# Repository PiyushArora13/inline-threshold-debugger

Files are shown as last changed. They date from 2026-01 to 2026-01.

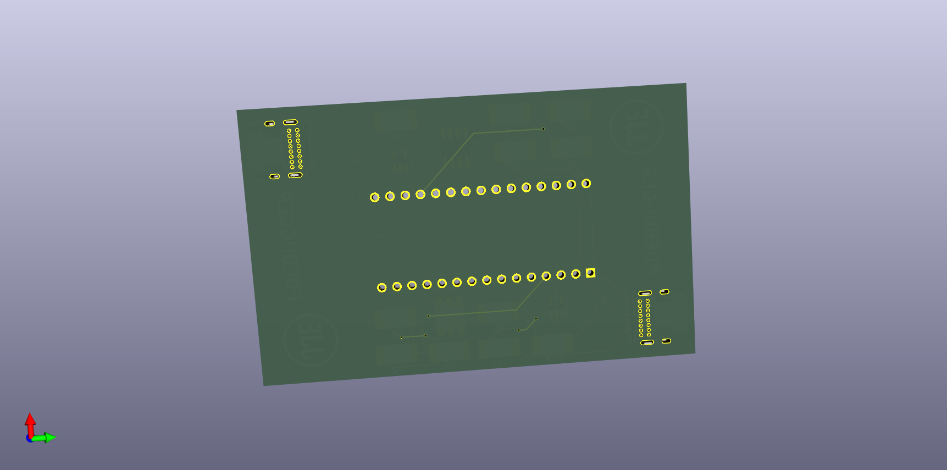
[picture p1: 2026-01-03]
Images/Bottom View.png

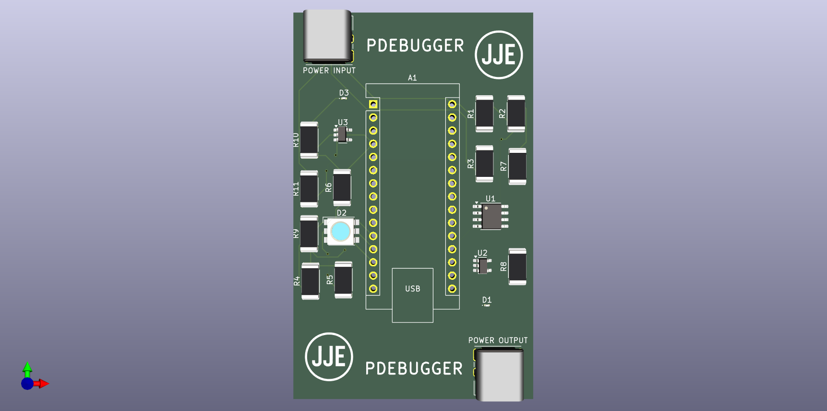
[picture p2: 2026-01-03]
Images/Top View.png

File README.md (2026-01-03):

# inline-threshold-debugger

Non-Intrusive USB-C Inline Diagnostic PCB for Master–Slave Systems

# Overview

This project presents a non-intrusive inline hardware debugger PCB designed for master–slave embedded architectures, where continuous electrical monitoring is required without altering normal system behavior. The board is placed directly in-line between master and slave nodes, enabling real-time observation of voltage and current characteristics while preserving signal integrity.

The design focuses on high-impedance sensing and comparator-based threshold detection, ensuring that monitored signals experience minimal loading and no functional disturbance. This approach allows the debugger to operate transparently within active systems, making it suitable for live diagnostics, validation, and safety monitoring.

A USB Type-C pass-through interface is used for both input and output, providing a compact, reversible, and standardized physical layer compatible with modern embedded and robotics platforms.

# System Architecture

The PCB is built around an Arduino Nano (ATmega328P), which serves as the central processing unit for data acquisition, threshold evaluation, and status indication. The microcontroller samples analog signals via its ADC and coordinates with dedicated comparator stages to classify operating conditions deterministically.

Current sensing is implemented using the ACS712 Hall-effect current sensor, providing galvanically isolated measurement with low insertion impact on the monitored path. This enables accurate current monitoring while maintaining electrical separation and system safety.

Voltage monitoring is achieved through a high-impedance sensing network followed by comparator stages configured with predefined threshold levels. Comparator outputs allow fast detection of limit violations independent of firmware execution latency, ensuring reliable indication under transient conditions.

The inline signal path is designed to maintain impedance continuity between master and slave devices, allowing the debugger PCB to function as a transparent diagnostic layer rather than an active system element.

# Threshold Evaluation and Visual Indication

Measured voltage and current parameters are continuously evaluated against predefined threshold regions. The system provides immediate visual feedback through:

Discrete LEDs indicating individual threshold events

An RGB LED representing overall system state:

Green – Normal / safe operating region

Yellow – Warning or near-limit condition

Red – Critical or unsafe operating condition

This hardware-level indication enables rapid fault identification without requiring external instruments or software-based debugging tools.

# Design Intent and Rationale

Non-intrusive monitoring: High-impedance sensing and isolated current measurement prevent disturbance of the original signal path.

Comparator-based thresholding: Ensures fast, deterministic response independent of microcontroller timing.

Inline architecture: Allows real-time diagnostics in active master–slave systems.

USB Type-C interface: Provides a compact, reversible, and standardized physical connection.

Separation of sensing and indication: Improves robustness and simplifies system-level fault analysis.

# Applications

Inline debugging of master–slave embedded systems

Power and signal integrity validation

Current and voltage health monitoring

Safety threshold enforcement in robotics and control systems

Rapid fault detection during system integration and testing

Project Status

Hardware: Prototype PCB designed and validated

Firmware: Threshold evaluation and visual indication logic implemented

Future work: Data logging, configurable thresholds, and host-side visualization

# Note on File Viewing

KiCad design files are stored in source format and are not rendered by GitHub. Please clone or download the repository and open it in KiCad to view schematics and PCB layouts. Rendered images are included for reference

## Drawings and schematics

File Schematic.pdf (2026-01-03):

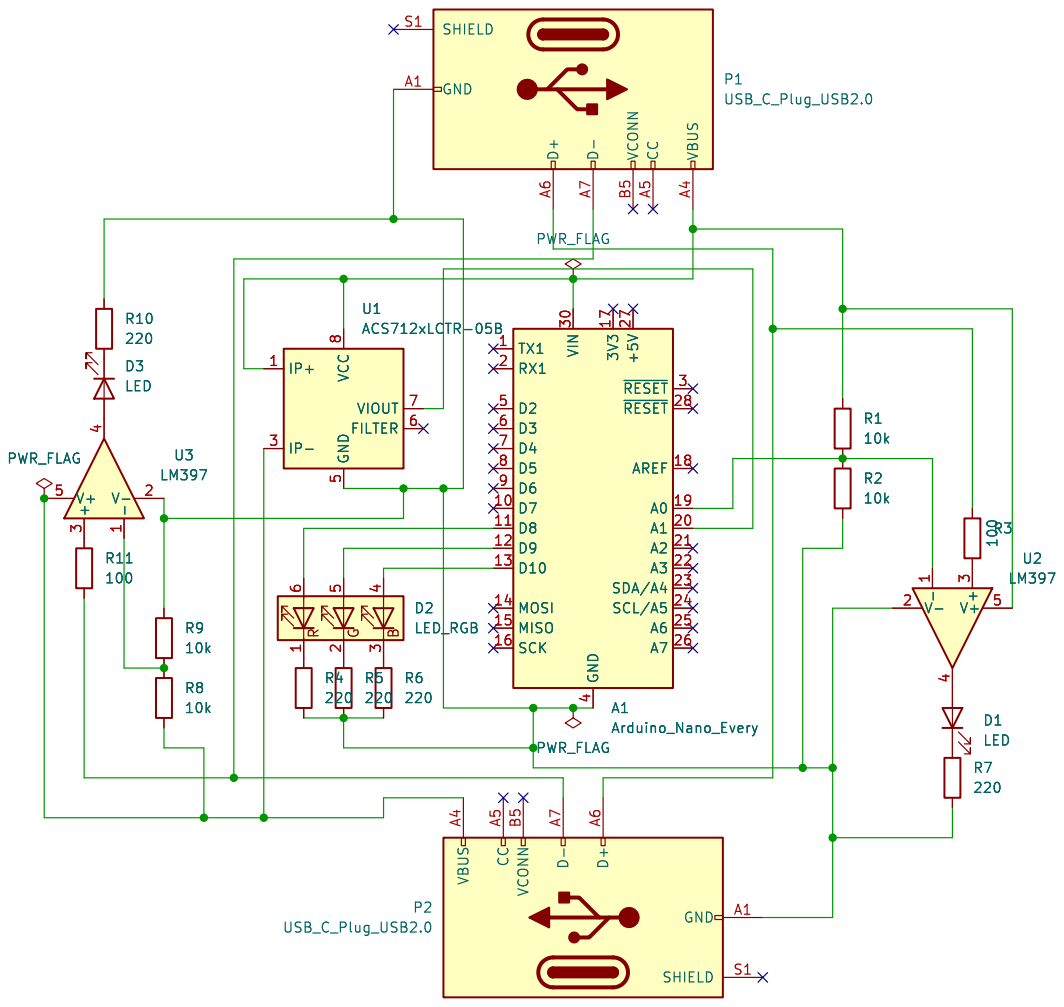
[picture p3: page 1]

4 D2 5 D3 6 D4 7 D5 8 D6 9 A1Arduino_Nano_Every GND A1 VBUS A4 CC A5 D+ A6 D- A7 VCONN B5 SHIELD S1 P1USB_C_Plug_USB2.0 R4

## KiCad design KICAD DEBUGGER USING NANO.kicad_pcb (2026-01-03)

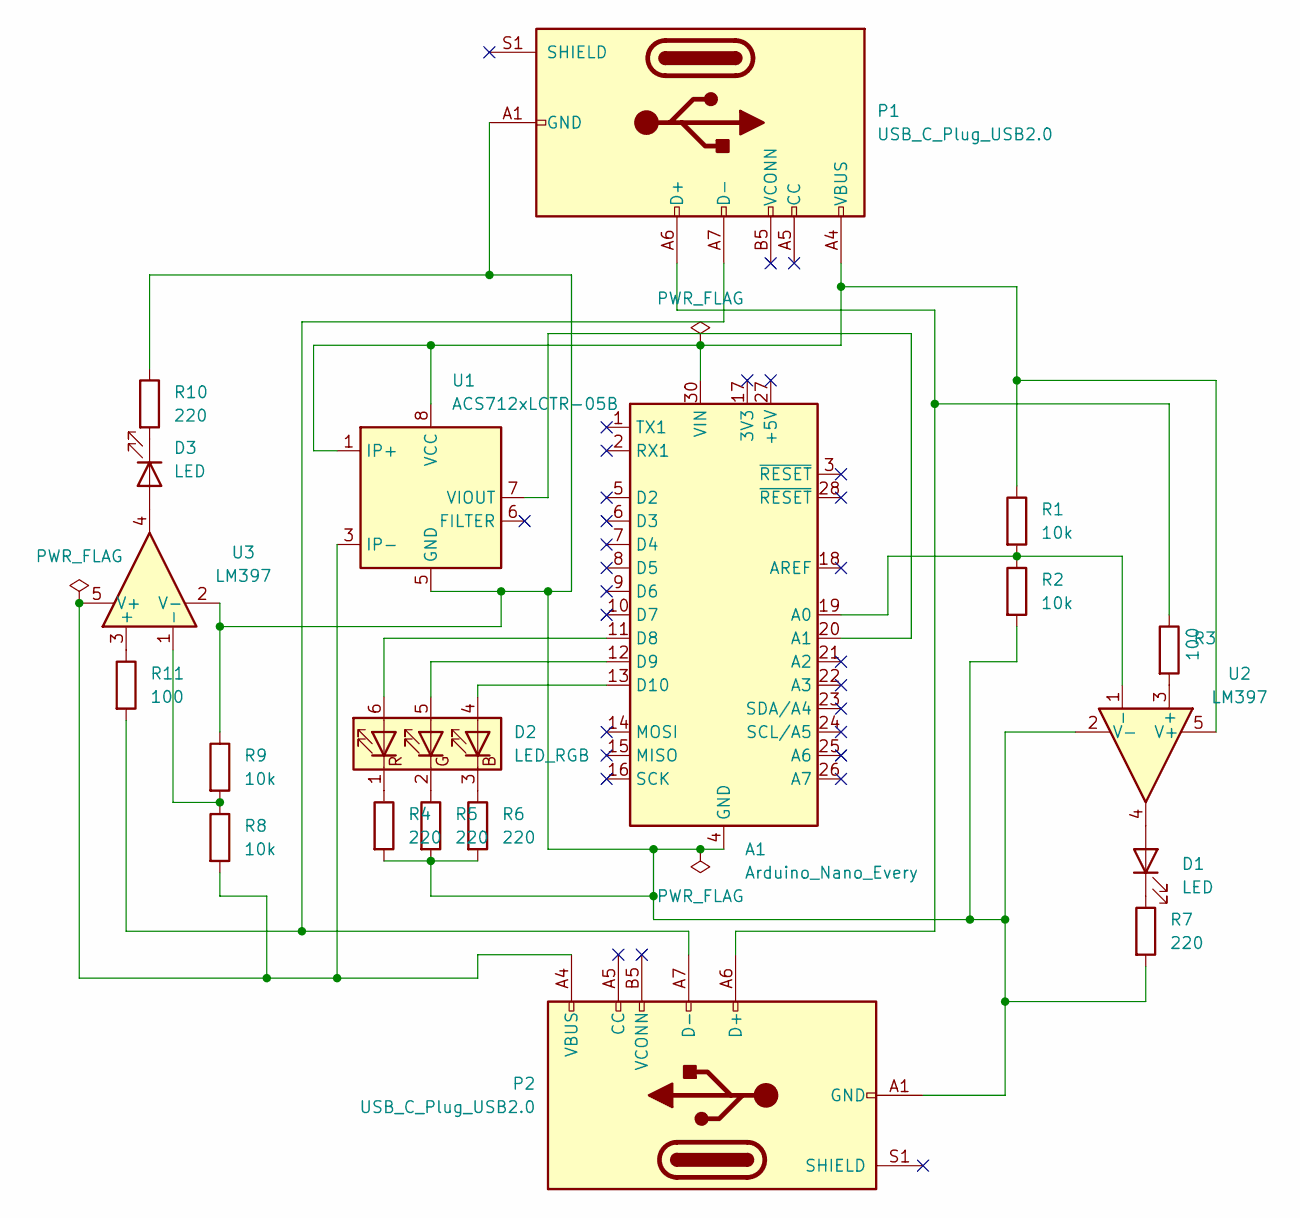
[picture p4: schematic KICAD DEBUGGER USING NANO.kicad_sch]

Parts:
A1: Arduino_Nano_Every; Arduino_Nano
D1, D3: LED; LED_0201_0603Metric
D2: LED_RGB; LED_RGB_5050-6
P1, P2: USB_C_Plug_USB2.0; USB_C_Receptacle_GCT_USB4085
R1, R2, R8, R9: 10k; R_2512_6332Metric
R3, R11: 100; R_2512_6332Metric
R4, R5, R6, R7, R10: 220; R_2512_6332Metric
U1: ACS712xLCTR-05B; SOIC-8_3.9x4.9mm_P1.27mm
U2, U3: LM397; SOT-23-5

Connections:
unnamed: A1.19 (A0), R1.2, R2.1, U2.1 (-)
unnamed: A1.20 (A1), U1.7 (VIOUT)
unnamed: A1.11 (D8), D2.6 (RA)
unnamed: A1.12 (D9), D2.5 (GA)
unnamed: A1.13 (D10), D2.4 (BA)
unnamed 5: A1.30 (VIN), P1.A4 (VBUS), P1.A9 (VBUS), P1.B4 (VBUS), P1.B9 (VBUS), R1.1, U1.1 (IP+), U1.2 (IP+), U1.8 (VCC), U2.5 (V+); also elsewhere on the board
unnamed: D1.2 (A), U2.4
unnamed: D1.1 (K), R7.1
unnamed: D2.3 (BK), R6.1
unnamed: D2.2 (GK), R5.1
unnamed: D2.1 (RK), R4.1
unnamed: D3.2 (A), U3.4
unnamed: D3.1 (K), R10.2
unnamed 13: P1.A6 (D+), P2.A6 (D+), R3.1; also elsewhere on the board
unnamed 14: P1.A7 (D-), P2.A7 (D-), R11.2; also elsewhere on the board
unnamed 15: A1.4 (GND), A1.29 (GND), P1.A1 (GND), P1.A12 (GND), P1.B1 (GND), P1.B12 (GND), P2.A1 (GND), P2.A12 (GND), P2.B1 (GND), P2.B12 (GND), R2.2, R4.2, R5.2, R6.2, R7.2, R9.1, R10.1, U1.5 (GND), U2.2 (V-), U3.2 (V-); also elsewhere on the board
unnamed: R3.2, U2.3 (+)
unnamed: R11.1, U3.3 (+)
unnamed: R8.1, R9.2, U3.1 (-)
unnamed 19: P2.A4 (VBUS), P2.A9 (VBUS), P2.B4 (VBUS), P2.B9 (VBUS), R8.2, U1.3 (IP-), U1.4 (IP-), U3.5 (V+); also elsewhere on the board

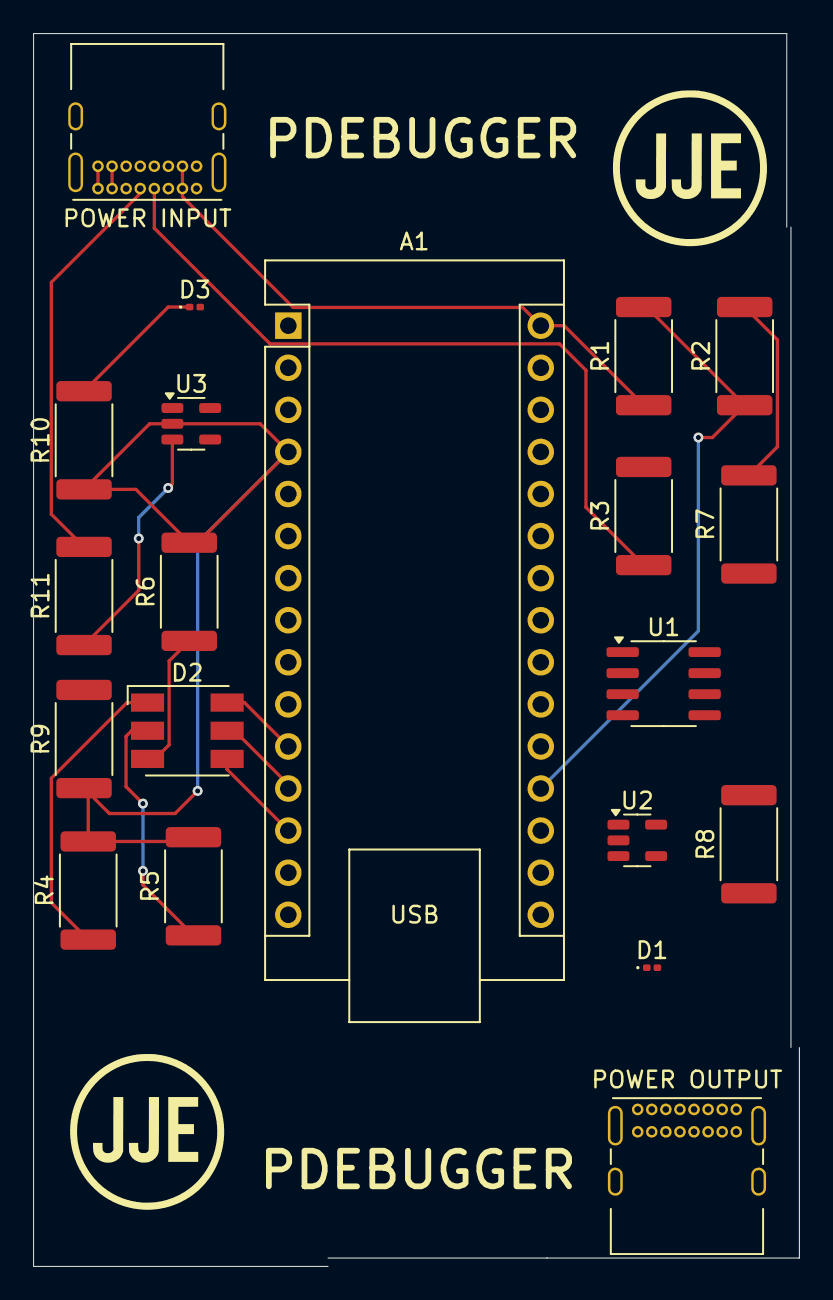
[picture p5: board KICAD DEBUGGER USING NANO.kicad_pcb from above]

Board: 2 copper layers, 46.2 x 74.4 mm, 20 parts (0 on the bottom side), 20 nets.

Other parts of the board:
POWER INPUT: USB_C_Plug_USB2.0; USB_C_Receptacle_GCT_USB4085
POWER OUTPUT: USB_C_Plug_USB2.0; USB_C_Receptacle_GCT_USB4085

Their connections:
unnamed 5: POWER INPUT.A4 (VBUS), POWER INPUT.A9 (VBUS), POWER INPUT.B4 (VBUS), POWER INPUT.B9 (VBUS); also elsewhere on the board
unnamed 13: POWER INPUT.A6 (D+), POWER OUTPUT.A6 (D+); also elsewhere on the board
unnamed 14: POWER INPUT.A7 (D-), POWER OUTPUT.A7 (D-); also elsewhere on the board
unnamed 15: POWER INPUT.A1 (GND), POWER INPUT.A12 (GND), POWER INPUT.B1 (GND), POWER INPUT.B12 (GND), POWER OUTPUT.A1 (GND), POWER OUTPUT.A12 (GND), POWER OUTPUT.B1 (GND), POWER OUTPUT.B12 (GND); also elsewhere on the board
unnamed 19: POWER OUTPUT.A4 (VBUS), POWER OUTPUT.A9 (VBUS), POWER OUTPUT.B4 (VBUS), POWER OUTPUT.B9 (VBUS); also elsewhere on the board
